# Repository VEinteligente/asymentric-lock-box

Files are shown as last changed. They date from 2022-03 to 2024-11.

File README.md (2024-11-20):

# Asymmetric Lock Box
An open source design for a educational tool to aid in the teaching of PGP or Public Key Cryptography for use in exercise.

R1

## Asymmetric Lock Box building
In this repository you will find the files necesary to make your Asymmetric Lock Box, in the folder [Asymmetric Lock Box](https://github.com/VEinteligente/asymentric-lock-box/tree/main/Asymmetric%20Lock%20Box) you can find tree folders: [Acrylic Lids](https://github.com/VEinteligente/asymentric-lock-box/tree/main/Asymmetric%20Lock%20Box/Acrylic%20Lids), [STEP Files](https://github.com/VEinteligente/asymentric-lock-box/tree/main/Asymmetric%20Lock%20Box/STEP%20Files) and [STL Files](https://github.com/VEinteligente/asymentric-lock-box/tree/main/Asymmetric%20Lock%20Box/STL%20Files).

In the file [Ensamblaje.PDF](https://github.com/VEinteligente/asymentric-lock-box/blob/main/Asymmetric%20Lock%20Box/Ensamblaje.PDF) you can see the all pieces of the box and and the recommended material, we recomended using PLA+ or PLA for the printed parts and acrilic for the lids, but you can try using other materials.

### Box Dimensions
* Length: 21.2cm

* Width: 16.7cm

* Depth: 2.7cm

### 3D Printing
For the 3D printing process you need the STL Files, so following the file [assembly](https://github.com/VEinteligente/asymentric-lock-box/blob/main/Asymmetric%20Lock%20Box/Ensamblaje.PDF) you will find which pieces and how many you need to print, and then you can find the STL file for each part.

**Note:** Piece #22 "arandela 2.2" is the same piece #21 "arandela 2", according to the [assembly](https://github.com/VEinteligente/asymentric-lock-box/blob/main/Asymmetric%20Lock%20Box/Ensamblaje.PDF) file. 

#### 3D Printer Settings
If you will use PLA+ filament we recomended the following settings:

* **Temperature:** 215°C

* **Nozzle:** 0,4mm

* **Layer Height:** 0.2mm

* **Outer wall Speed:** 25mm/s

* **Infill:** 10%

### Acrylic Lids
For lids we recomended using acrylic, but you can use others materials like wood or any other.
In the folder [Acrylic Lids](https://github.com/VEinteligente/asymentric-lock-box/tree/main/Asymmetric%20Lock%20Box/Acrylic%20Lids) you can dowload the files to cut and laser engraving the lids.

### Model to edit
The folder [STEP Files](https://github.com/VEinteligente/asymentric-lock-box/tree/main/Asymmetric%20Lock%20Box/STEP%20Files) has the file for each part and you can make little changes.

### Assembly Elements
#### Pieces
See the file [assembly](https://github.com/VEinteligente/asymentric-lock-box/blob/main/Asymmetric%20Lock%20Box/Ensamblaje.PDF)

**UPDATE**: Pieces No.: 16 ([LlaveA.STL](https://github.com/VEinteligente/asymentric-lock-box/blob/main/Asymmetric%20Lock%20Box/STL%20Files/LlaveA.STL)) and 17 ([CabezaLlaveA.STL](https://github.com/VEinteligente/asymentric-lock-box/blob/main/Asymmetric%20Lock%20Box/STL%20Files/CabezaLlaveA.STL)), can be replaced by the piece [LlaveCilindroA.STL](https://github.com/VEinteligente/asymentric-lock-box/blob/main/Asymmetric%20Lock%20Box/STL%20Files/LlaveCilindroA.STL), while the pieces No.: 18 ([LlaveB.STL](https://github.com/VEinteligente/asymentric-lock-box/blob/main/Asymmetric%20Lock%20Box/STL%20Files/LlaveB.STL)) and 19 ([CabezaLlaveB.STL](https://github.com/VEinteligente/asymentric-lock-box/blob/main/Asymmetric%20Lock%20Box/STL%20Files/CabezaLlaveB.STL)) can be replaced by the piece [LlaveCilindroB.STL](https://github.com/VEinteligente/asymentric-lock-box/blob/main/Asymmetric%20Lock%20Box/STL%20Files/LlaveCilindroB.STL).

#### Screws and others
* 4 x 1/4" Pan Head Sheet Metal Screws (17 items)

* Mini Rubber Bands (2 items)

#### Recomended Tools

* Cutter

* Sandpaper

* Screwdriver

* Superglue

**[For more information](https://conexionsegura.org/box)**

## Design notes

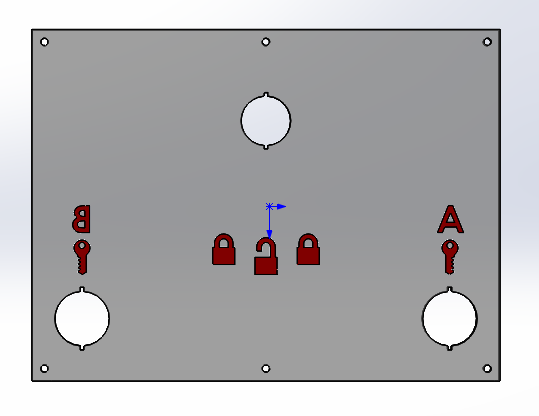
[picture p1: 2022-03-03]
Asymmetric Lock Box/STL Files/Acrilico3mm.PNG

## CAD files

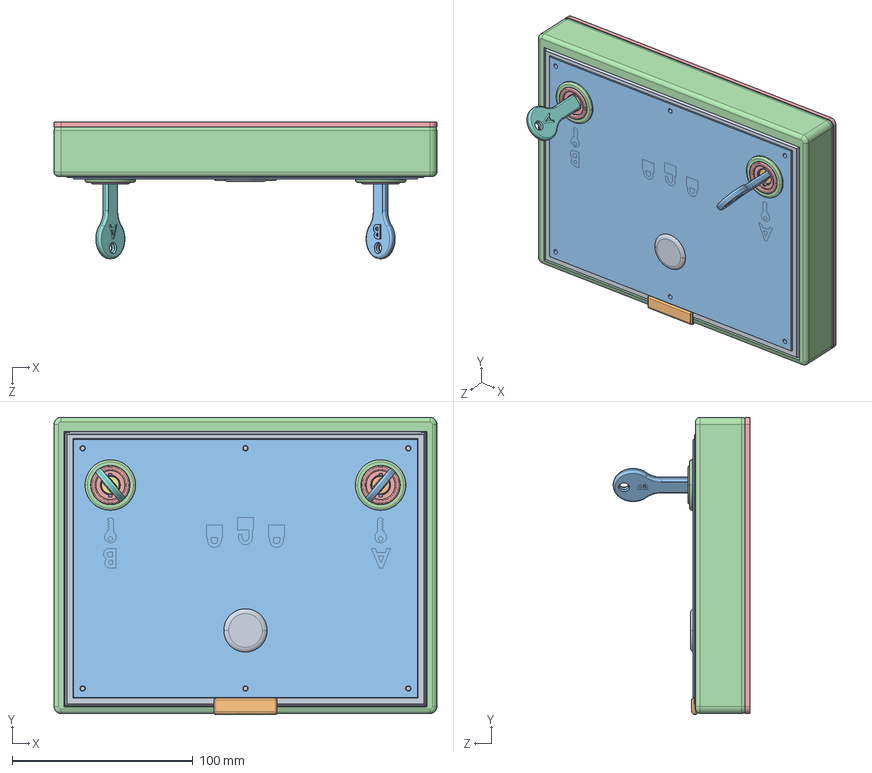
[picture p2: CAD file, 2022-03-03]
Asymmetric Lock Box/STEP Files/Ensamblaje1.STEP
212.0 x 164.6 x 75.6 mm
Tapa
Pestaña
AcrilicoTapa
Marco
AcrilicoFondo
Pasador x 2
Nivelador1 x 2
Leva
BaseLeva
ArandelaLeva
Pestillo1 x 2
BaseCerradura x 2
TapaCerradura x 2
CilindroA
CabezaLlaveA
LlaveA
CilindroB
CabezaLlaveB
LlaveB
Arandela1 x 4
Arandela2 x 2
Arandela2.2 x 2

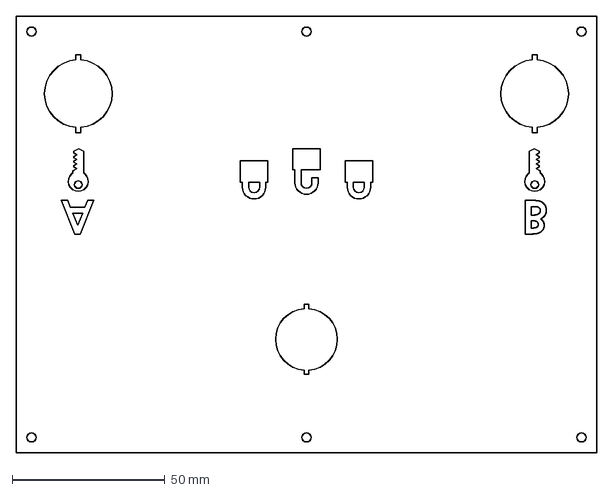
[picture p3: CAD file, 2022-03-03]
Asymmetric Lock Box/Acrylic Lids/Acrilico3mm.DXF
190.2 x 142.9 mm

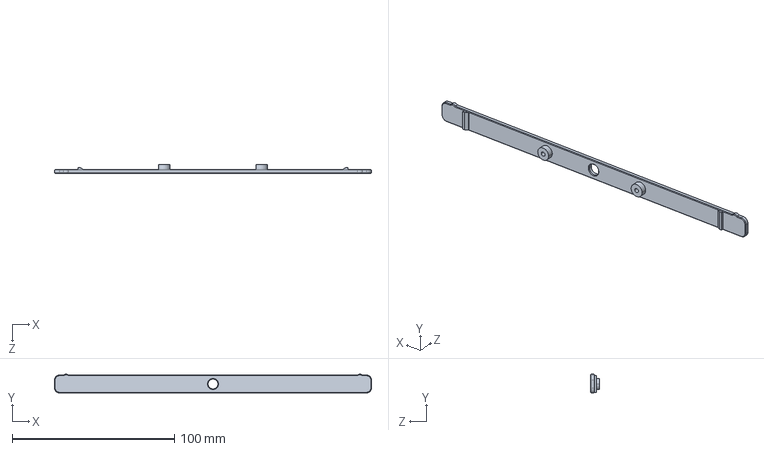
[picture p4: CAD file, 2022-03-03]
Asymmetric Lock Box/STEP Files/Pasador.STEP
195.3 x 11.6 x 5.40 mm

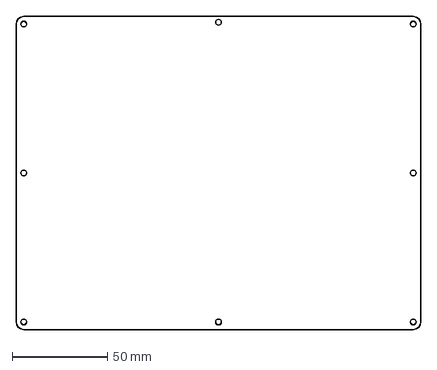
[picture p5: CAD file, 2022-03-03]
Asymmetric Lock Box/Acrylic Lids/Fondo-2mm.DXF
212.0 x 164.0 mm

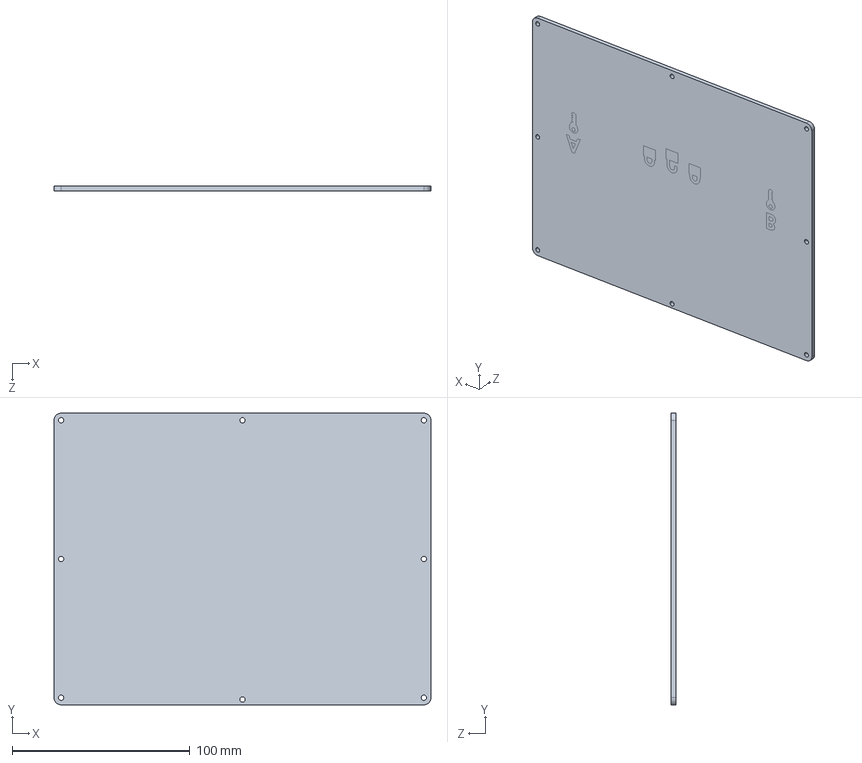
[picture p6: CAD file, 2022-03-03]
Asymmetric Lock Box/STEP Files/AcrilicoFondo.STEP
212.0 x 164.0 x 2.70 mm

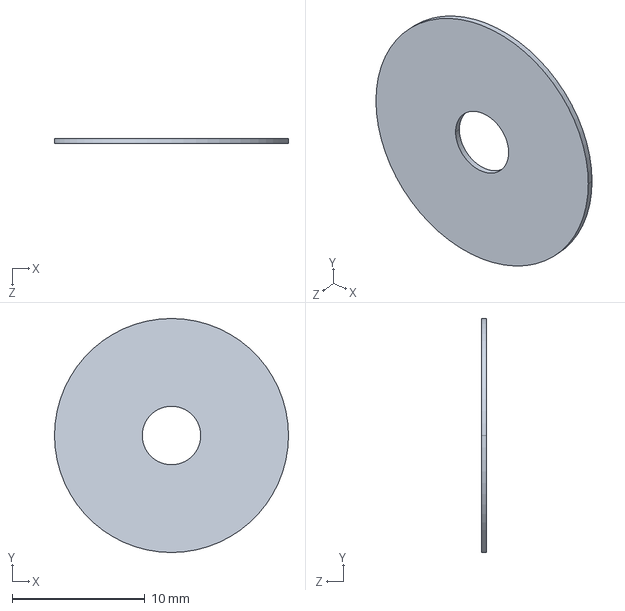
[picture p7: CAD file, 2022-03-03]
Asymmetric Lock Box/STEP Files/ArandelaLeva.STEP
17.6 x 17.6 x 0.4 mm

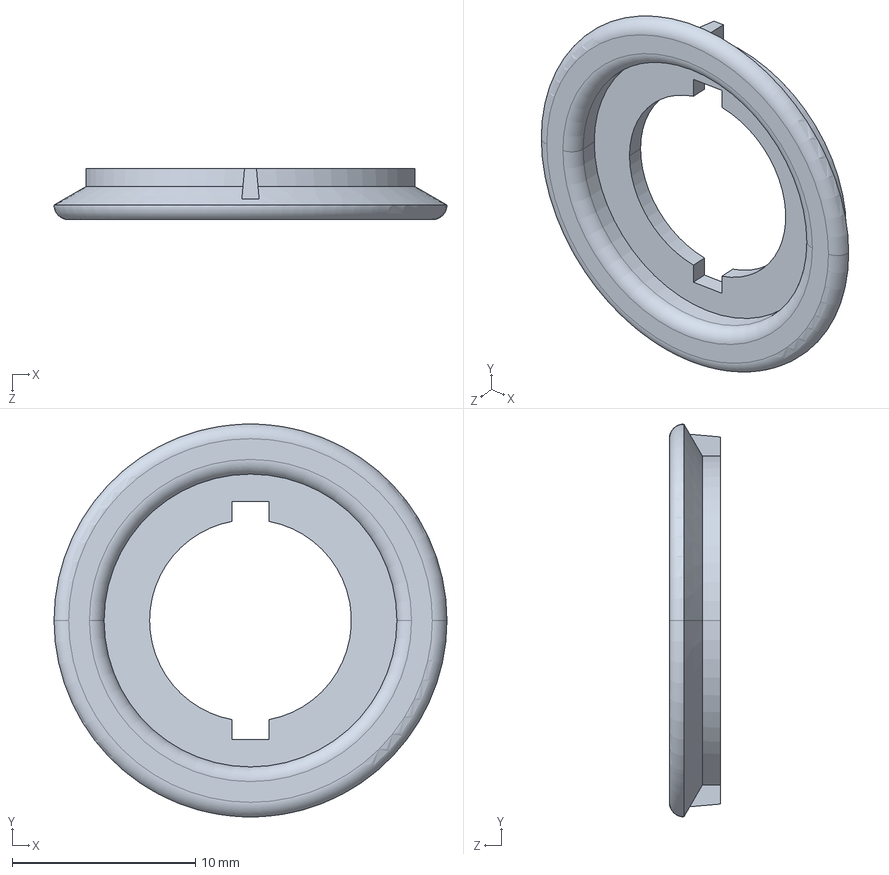
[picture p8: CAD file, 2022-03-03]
Asymmetric Lock Box/STEP Files/TapaCerradura.STEP
21.4 x 21.4 x 2.80 mm

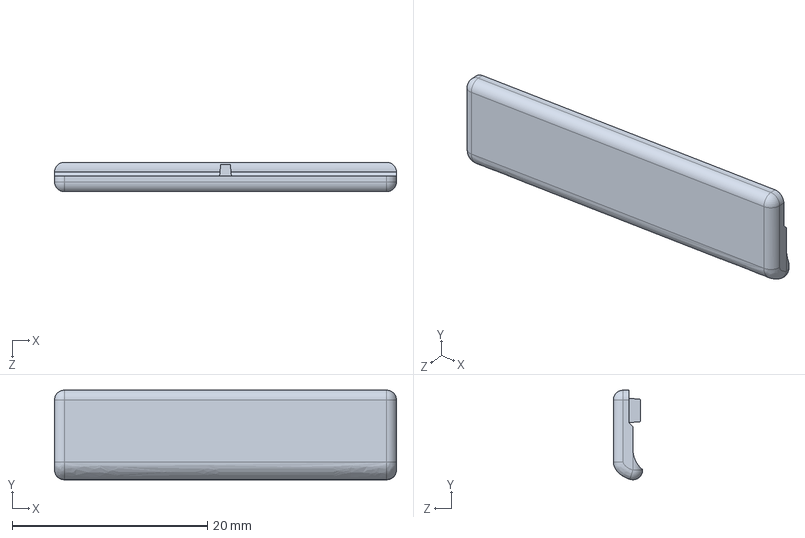
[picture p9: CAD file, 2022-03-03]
Asymmetric Lock Box/STEP Files/Pestaña.STEP
35.0 x 9.17 x 3.00 mm

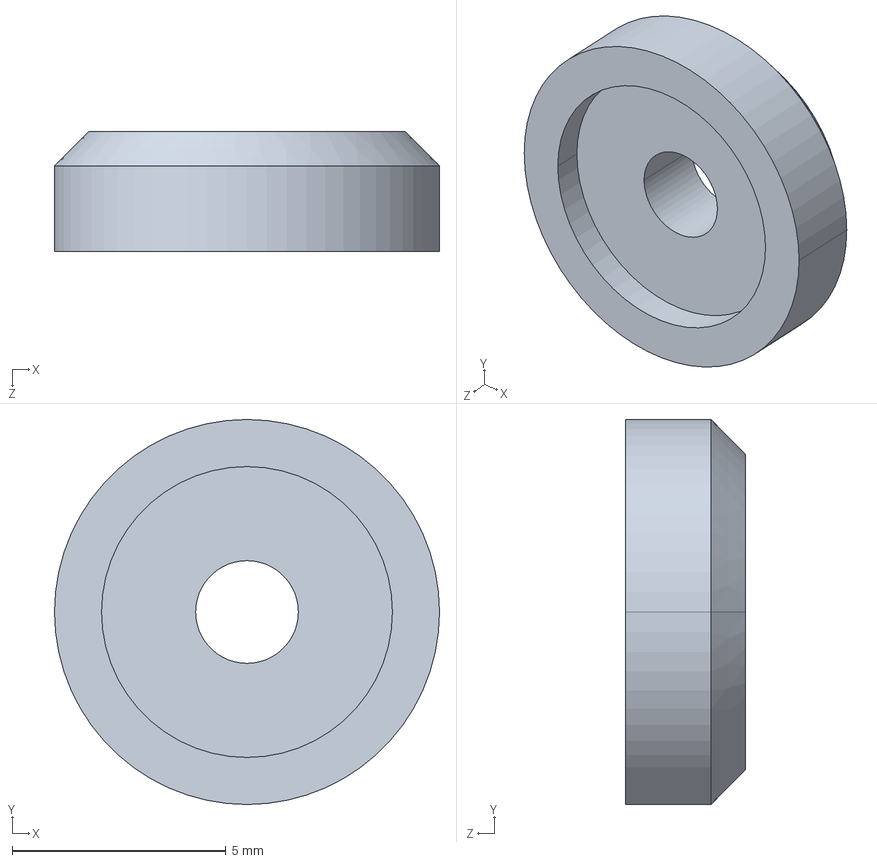
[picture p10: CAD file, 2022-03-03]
Asymmetric Lock Box/STEP Files/Arandela2.STEP
9.00 x 9.00 x 2.80 mm

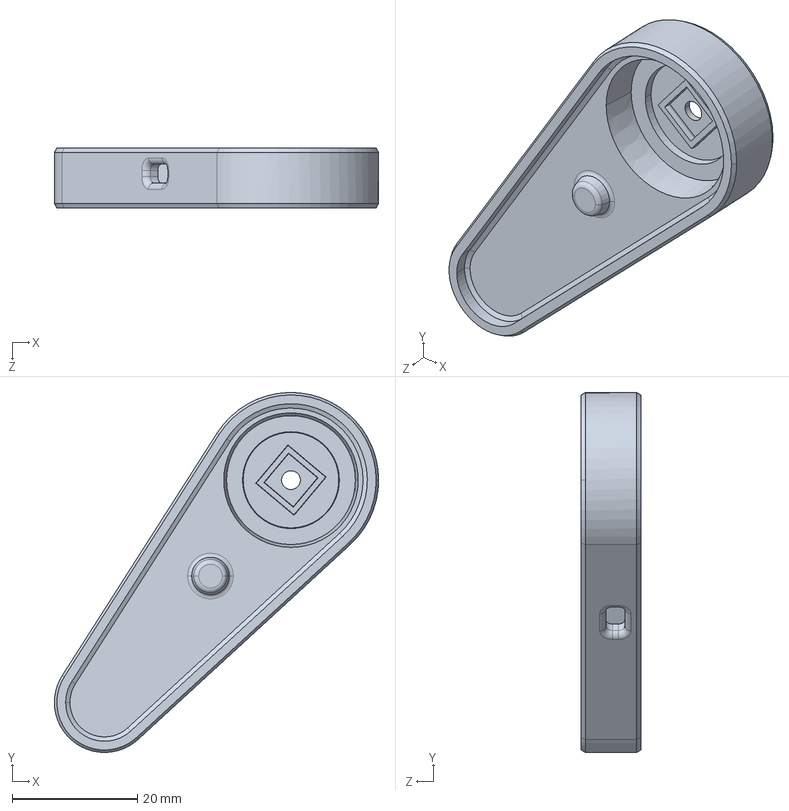
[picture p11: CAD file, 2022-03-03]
Asymmetric Lock Box/STEP Files/Pestillo.STEP
51.8 x 57.5 x 9.60 mm

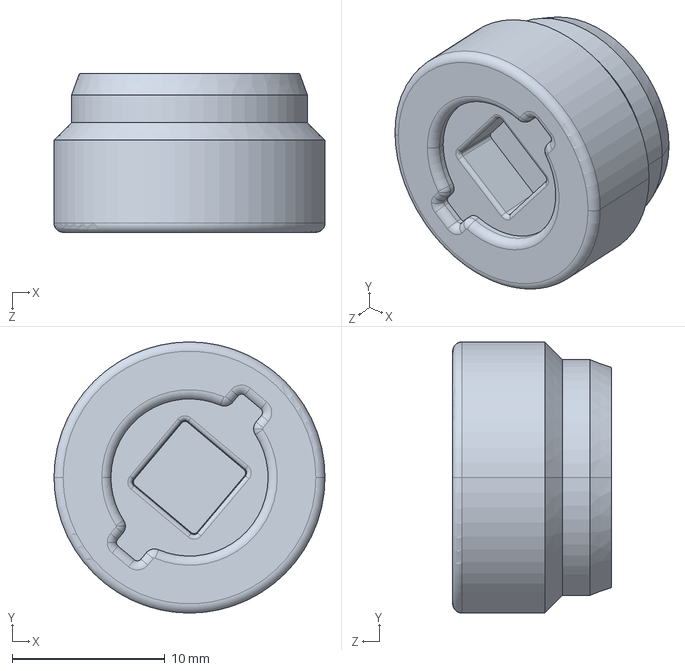
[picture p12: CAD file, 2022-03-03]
Asymmetric Lock Box/STEP Files/CilindroB.STEP
17.8 x 17.8 x 10.4 mm

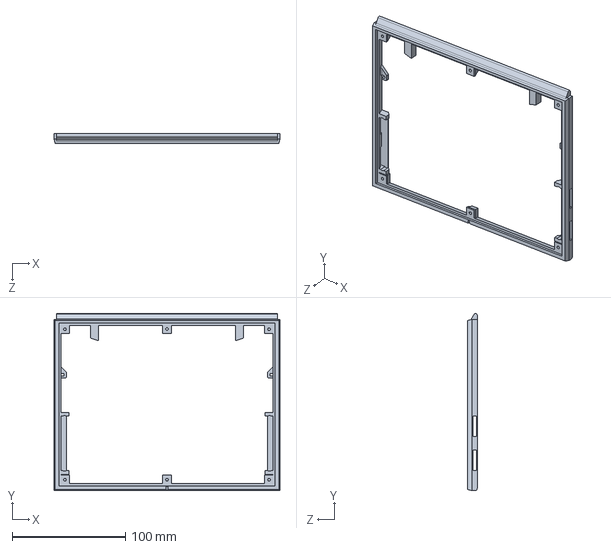
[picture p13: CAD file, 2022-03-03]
Asymmetric Lock Box/STEP Files/Tapa.STEP
199.6 x 156.6 x 8.39 mm

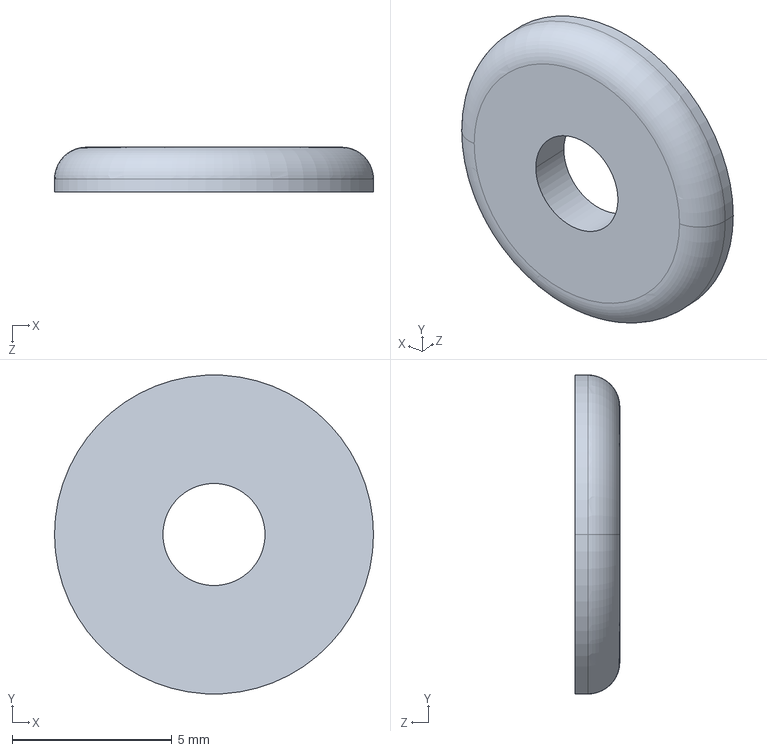
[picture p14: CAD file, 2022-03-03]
Asymmetric Lock Box/STEP Files/Arandela1.STEP
10.00 x 9.99 x 1.40 mm

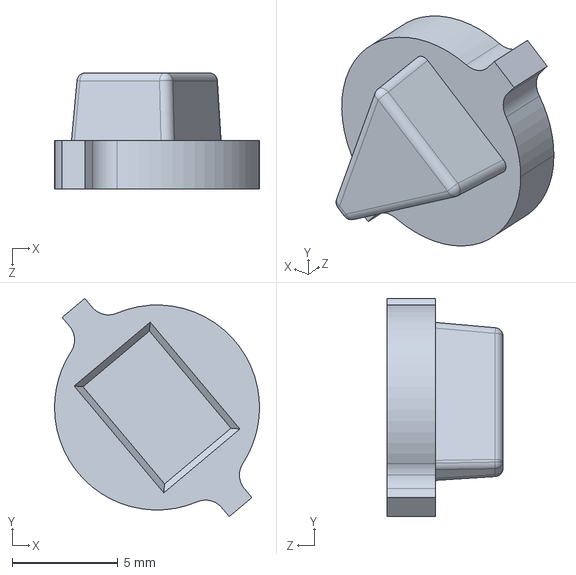
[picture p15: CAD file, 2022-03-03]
Asymmetric Lock Box/STEP Files/CabezaLlaveA.STEP
9.70 x 10.3 x 5.50 mm

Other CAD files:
Asymmetric Lock Box/STEP Files/CilindroA.STEP
Asymmetric Lock Box/STEP Files/AcrilicoTapa.STEP
Asymmetric Lock Box/STEP Files/BaseCerradura.STEP
Asymmetric Lock Box/STEP Files/CabezaLlaveB.STEP
Asymmetric Lock Box/Acrylic Lids/Acrilico-3mm.DWG
Asymmetric Lock Box/STEP Files/BaseLeva.STEP
Asymmetric Lock Box/STEP Files/Leva.STEP
Asymmetric Lock Box/STEP Files/LlaveA.STEP
Asymmetric Lock Box/STEP Files/LlaveB.STEP
Asymmetric Lock Box/STEP Files/Marco.STEP
Asymmetric Lock Box/STEP Files/Nivelador.STEP
Asymmetric Lock Box/STL Files/Arandela1.STL
Asymmetric Lock Box/STL Files/Arandela2.STL
Asymmetric Lock Box/STL Files/ArandelaLeva.STL
Asymmetric Lock Box/STL Files/BaseCerradura.STL
Asymmetric Lock Box/STL Files/BaseLeva.STL
Asymmetric Lock Box/STL Files/CabezaLlaveA.STL
Asymmetric Lock Box/STL Files/CabezaLlaveB.STL
Asymmetric Lock Box/STL Files/Leva.STL
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

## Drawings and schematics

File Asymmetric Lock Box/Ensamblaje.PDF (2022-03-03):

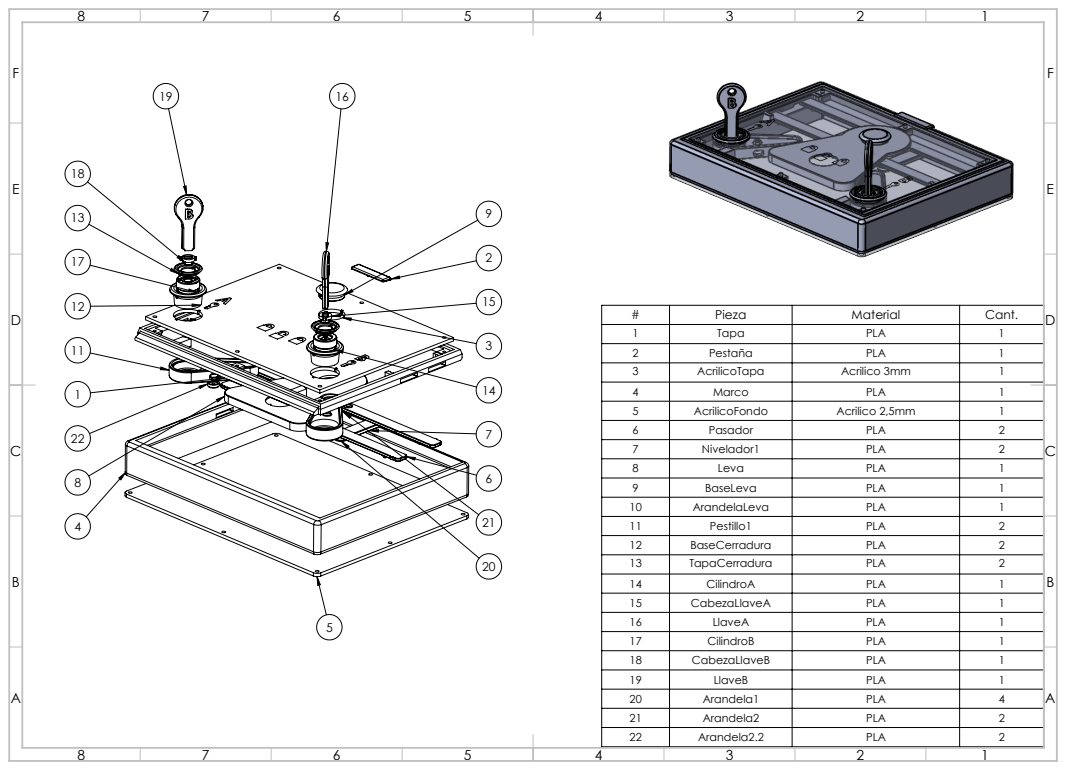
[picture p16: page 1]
Pieza; Material; Cant. 1; Tapa; PLA; Pestaña; AcrilicoTapa; Acrilico 3mm; Marco; AcrilicoFondo; Acrilico 2,5mm; Pasador; Nivelador1; Leva; BaseLeva

12 | BaseCerradura | PLA | 2
13 | TapaCerradura | PLA | 2
14 | CilindroA | PLA | 1
15 | CabezaLlaveA | PLA | 1
16 | LlaveA | PLA | 1
17 | CilindroB | PLA | 1
18 | CabezaLlaveB | PLA | 1
19 | LlaveB | PLA | 1
20 | Arandela1 | PLA | 4
21 | Arandela2 | PLA | 2
22 | Arandela2.2 | PLA | 2
